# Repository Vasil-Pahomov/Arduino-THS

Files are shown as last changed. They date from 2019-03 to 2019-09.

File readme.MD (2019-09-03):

# General
This is Arduno-based air quality sensor and logger.
The following air quality parameters are measured:
- Temperature
- Humidity
- CO2 level
- total volatile organic compound (TVOC) level
- particle matter (dust) PM1.0, PM2.5 and PM10 levels

It can be powered either with batteries (I used 18560 recharge lithium) or with USB power supply.
The sensor stores data on MicroSD card and is able to download it to companion application with Bluetooth. An Android companion is designed: https://github.com/Vasil-Pahomov/AQS-Android or https://github.com/AlexeyKatsuro/ABTEx

# Circuit
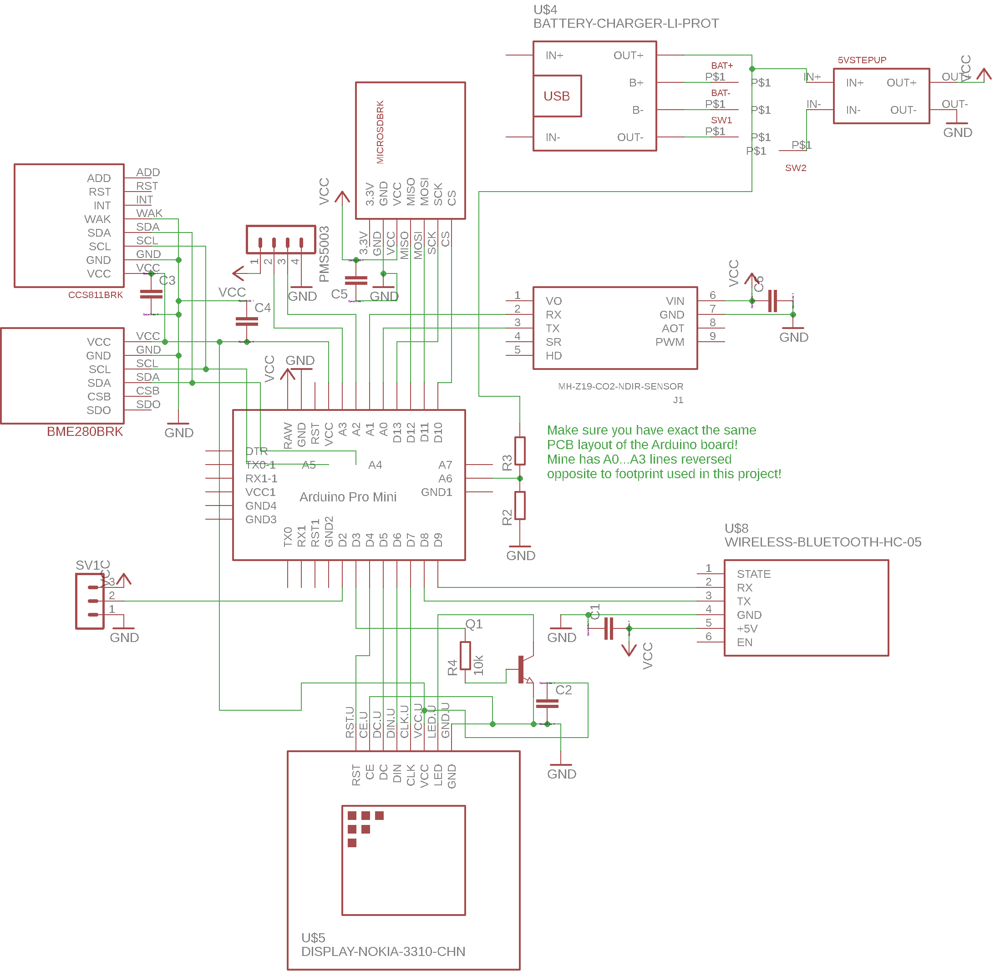
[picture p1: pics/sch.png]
Circuit diagram


# Part list

| Part | Image |
| ---- | ----- |
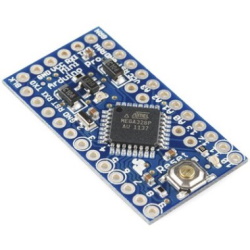
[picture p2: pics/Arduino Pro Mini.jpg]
| Arduino Pro Mini (3.3V) |  |
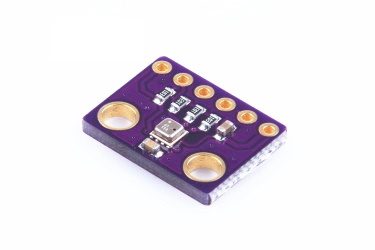
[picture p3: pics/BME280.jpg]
| BME280 temperature and humidity sensor board |  |
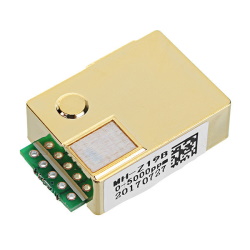
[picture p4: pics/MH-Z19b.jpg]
| MH-Z19B CO2 sensor |  |
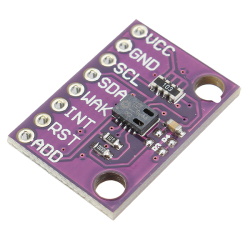
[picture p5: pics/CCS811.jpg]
| CCS811 TVOC sensor board |  |
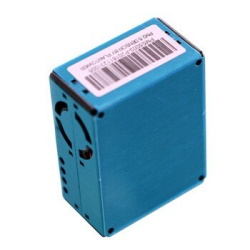
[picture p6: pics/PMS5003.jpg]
| PMS5003 dust sensor |  |
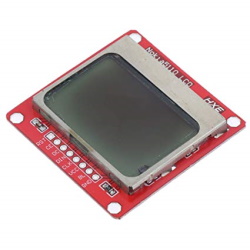
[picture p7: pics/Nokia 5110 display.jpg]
| Nokia 5110 LCD |  |
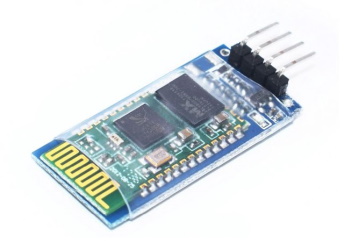
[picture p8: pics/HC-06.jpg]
| HC-06 bluetooth board |  |
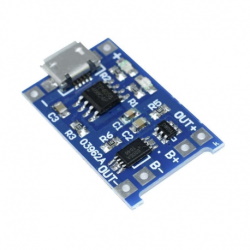
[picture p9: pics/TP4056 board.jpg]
| TP4056 charger board |  |
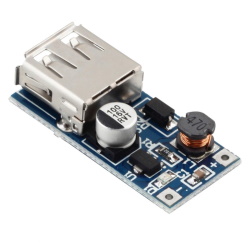
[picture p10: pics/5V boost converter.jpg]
| 5V boost converter |  |

# Log file format
Files are numbered starting from 0.log. Each file 10000 records. Record structure is defined in SDLog.h.
Once file numbers overcome 4000, it starts to delete files from the beginning.
Number of current file being written is stored in file named 'i' (2-byte unsigned word)

# Protocol format
## General
Organized as asyncronous messaging protocol. That is, both phone and sensor can send messages to each other. In fact, some messages resemble classis client-server communication.
## Message structure
| Field | Bytes | Description |
| ----- | ----- | --- |
| SGN | 2 | Signature=0xDEAF  |
| TYPE | 1 | Message type |
| DATA | ? | Message data, length depends on message type |

## Phone messages
### Sync time
TYPE=0x00
Sends current time to the sensor for sync up

| Field | Bytes | Description |
| ----- | ----- | --- |
| TIME | 4 | Unix timestamp |

### Read data
TYPE=0x01
Triggers sending data from the sensor

| Field | Bytes | Description |
| ----- | ----- | --- |
| FROMIDX | 4 | Index of starting record to read (including) |
| TOIDX | 4 | Index of ending record to read (including) |

### Reset storage
TYPE=0x02
Resets the storage (starts writing storage data anew)

The command has no body

### Calibrate CO2 sensor
TYPE=0x03
Sends calibration command to CO2 sensor. The sensor MUST be at least 20 minutes at open air environment (400 PPM).

The command has no body

## Sensor messages
### Status
TYPE=0x00

| Field | Bytes | Description |
| ----- | ----- | --- |
| STAT | 1 | Status:  0x00 if everything is OK, detailed see below |
| BAT | 1 | Battery percentage |
| LOGIDX | 4 | Number of last logged record (sequential, never overflows), returns 0xFFFFFFFF when there's SD card error |
| DATA | sizeof(Data) | Last sensor readings, Data structure |

#### Status byte
Zero value means OK, one - failure

| Bit | Description |
| ----- | --- |
| 0 | BME sensor |
| 1 | MH-Z19 sensor |
| 2 | PMS5003 sensor |
| 3 | CCS811 sensor |
| 4 | SD card |
| 5 | Time was synchronized |
| 6 | RESERVED (always 0) |
| 7 | RESERVED (always 0) |

### Data
| Field | Bytes | Description |
| ----- | ----- | --- |
| FROMIDX | 4 | Index of starting record |
| TOIDX | 4 | Index of ending record (including) |
| DATA | sizeof(Data)*N | Data records, N=TOIDX-FROMIDX |

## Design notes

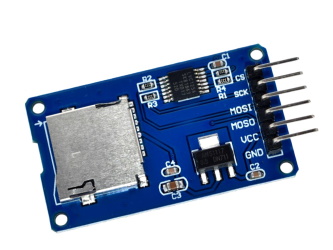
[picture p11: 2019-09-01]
pics/MicroSD slot.jpg

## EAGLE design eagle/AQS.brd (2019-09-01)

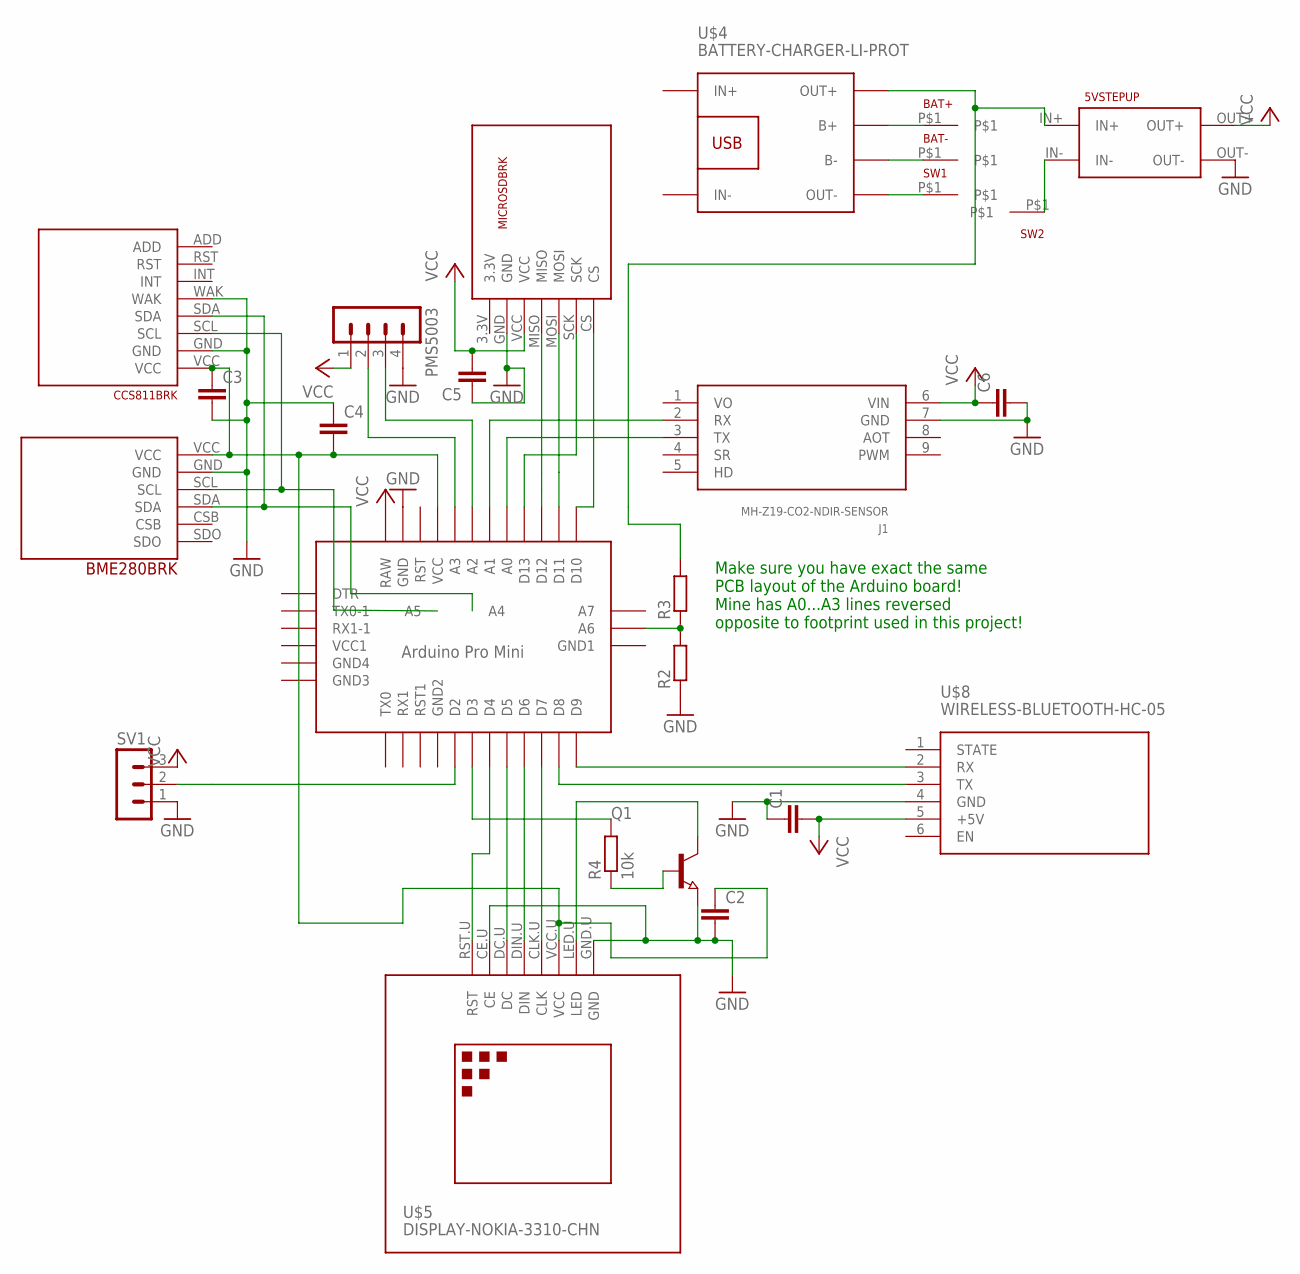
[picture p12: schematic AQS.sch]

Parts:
BAT+: PIN
BAT-: PIN
C1, C2, C3, C4, C5, C6: CC1206; C1206
J1: MH-Z19-CO2-NDIR-SENSOR; MH-Z19
PMS5003: MA04-1
Q1: NPN-TRANSISTOR_SOT23; SOT23
R2, R3: R-EU_0207/10; 0207/10
R4: 10k; 0207/10
SV1: MA03-1
SW1, SW2: PIN
U$1: ABK-PRO-MINI
U$2: BME280BRK
U$3: 5VSTEPUP
U$4: BATTERY-CHARGER-LI-PROT
U$5: DISPLAY-NOKIA-3310-CHN
U$6: CCS811BRK
U$7: MICROSDBRK
U$8: WIRELESS-BLUETOOTH-HC-05

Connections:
3.3V: U$7.3.3V
33V: C2.1, C3.1, C4.2, U$1.VCC, U$2.VCC, U$5.VCC.U (VCC), U$6.VCC
GND: C1.1, C2.2, C3.2, C4.1, C5.1, C6.2, J1.7 (GND), PMS5003.4, Q1.2 (E), R2.1, SV1.1, U$1.GND, U$2.GND, U$3.OUT-, U$5.CE.U (CE), U$5.GND.U (GND), U$6.GND, U$6.WAK, U$7.GND, U$8.4 (GND)
unnamed: BAT+.P$1, U$4.B+
unnamed: BAT-.P$1, U$4.B-
unnamed: R3.2, U$3.IN+, U$4.OUT+
unnamed: SW2.P$1, U$3.IN-
unnamed: U$1.A4, U$2.SDA, U$6.SDA
unnamed: U$1.A5, U$2.SCL, U$6.SCL
unnamed: U$1.D7, U$5.CLK.U (CLK)
unnamed: U$1.D6, U$5.DIN.U (DIN)
unnamed: U$1.D5, U$5.DC.U (DC)
unnamed: U$1.D4, U$5.RST.U (RST)
unnamed: Q1.3 (C), U$5.LED.U (LED)
unnamed: SW1.P$1, U$4.OUT-
unnamed: U$1.D9, U$8.2 (RX)
unnamed: U$1.D10, U$7.CS
unnamed: U$1.D11, U$7.MOSI
unnamed: U$1.D12, U$7.MISO
unnamed: U$1.D13, U$7.SCK
unnamed: J1.3 (TX), U$1.A0
unnamed: J1.2 (RX), U$1.A1
unnamed: U$1.D8, U$8.3 (TX)
unnamed: SV1.2, U$1.D2
unnamed: PMS5003.3, U$1.A2
unnamed: PMS5003.2, U$1.A3
unnamed: R2.2, R3.1, U$1.A6
unnamed: Q1.1 (B), R4.1
unnamed: R4.2, U$1.D3
VCC: C1.2, C5.2, C6.1, J1.6 (VIN), PMS5003.1, SV1.3, U$1.RAW, U$3.OUT+, U$7.VCC, U$8.5 (+5V)
VO: J1.1 (VO)

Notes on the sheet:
Make sure you have exact the same PCB layout of the Arduino board! Mine has A0...A3 lines reversed opposite to footprint used in this project!

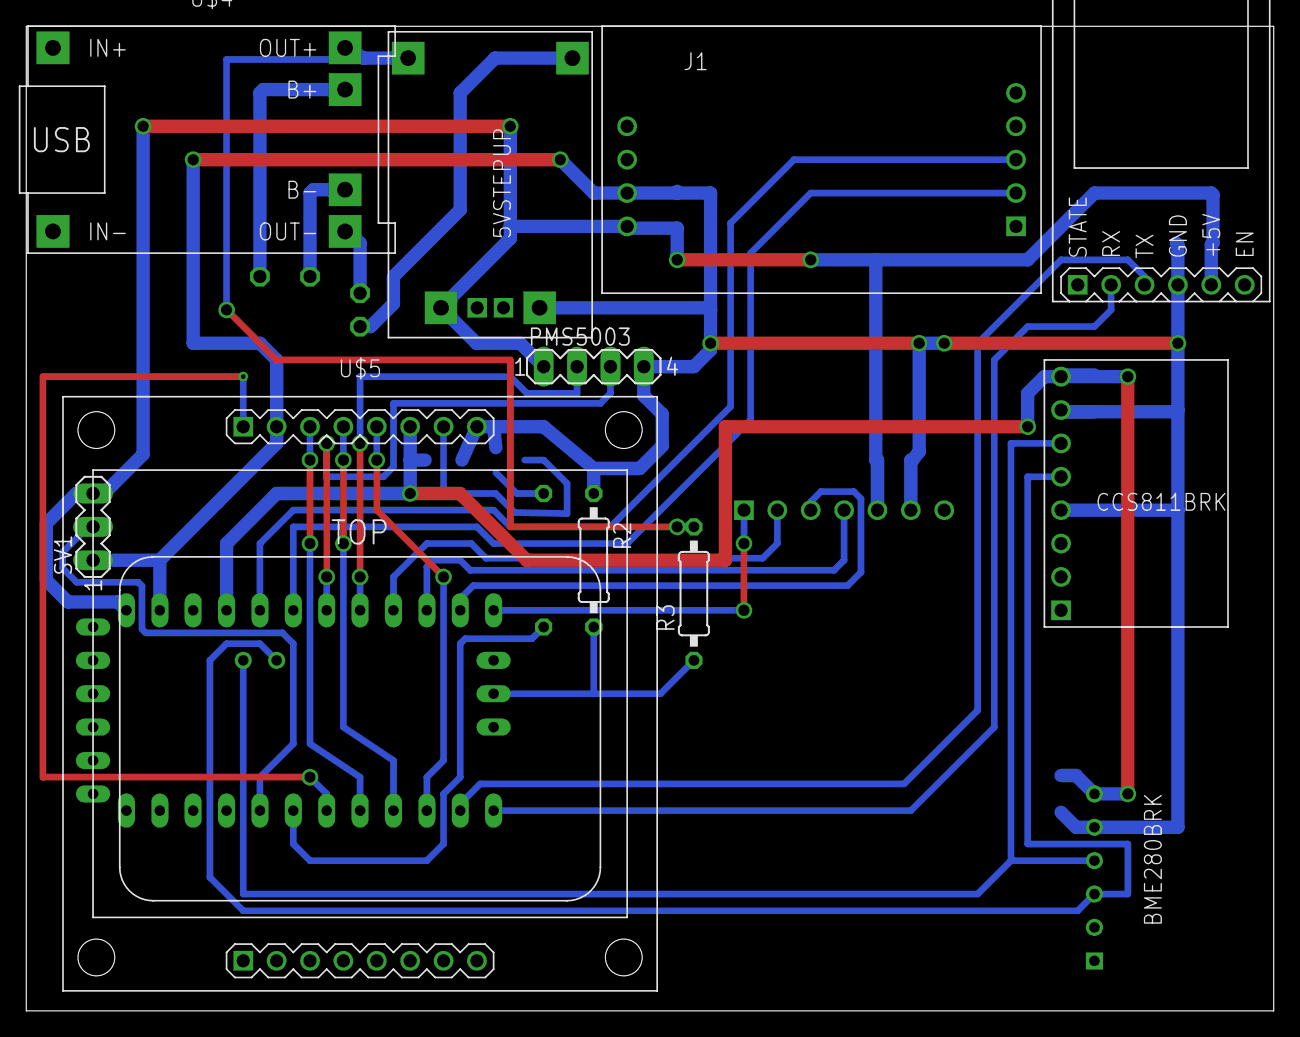
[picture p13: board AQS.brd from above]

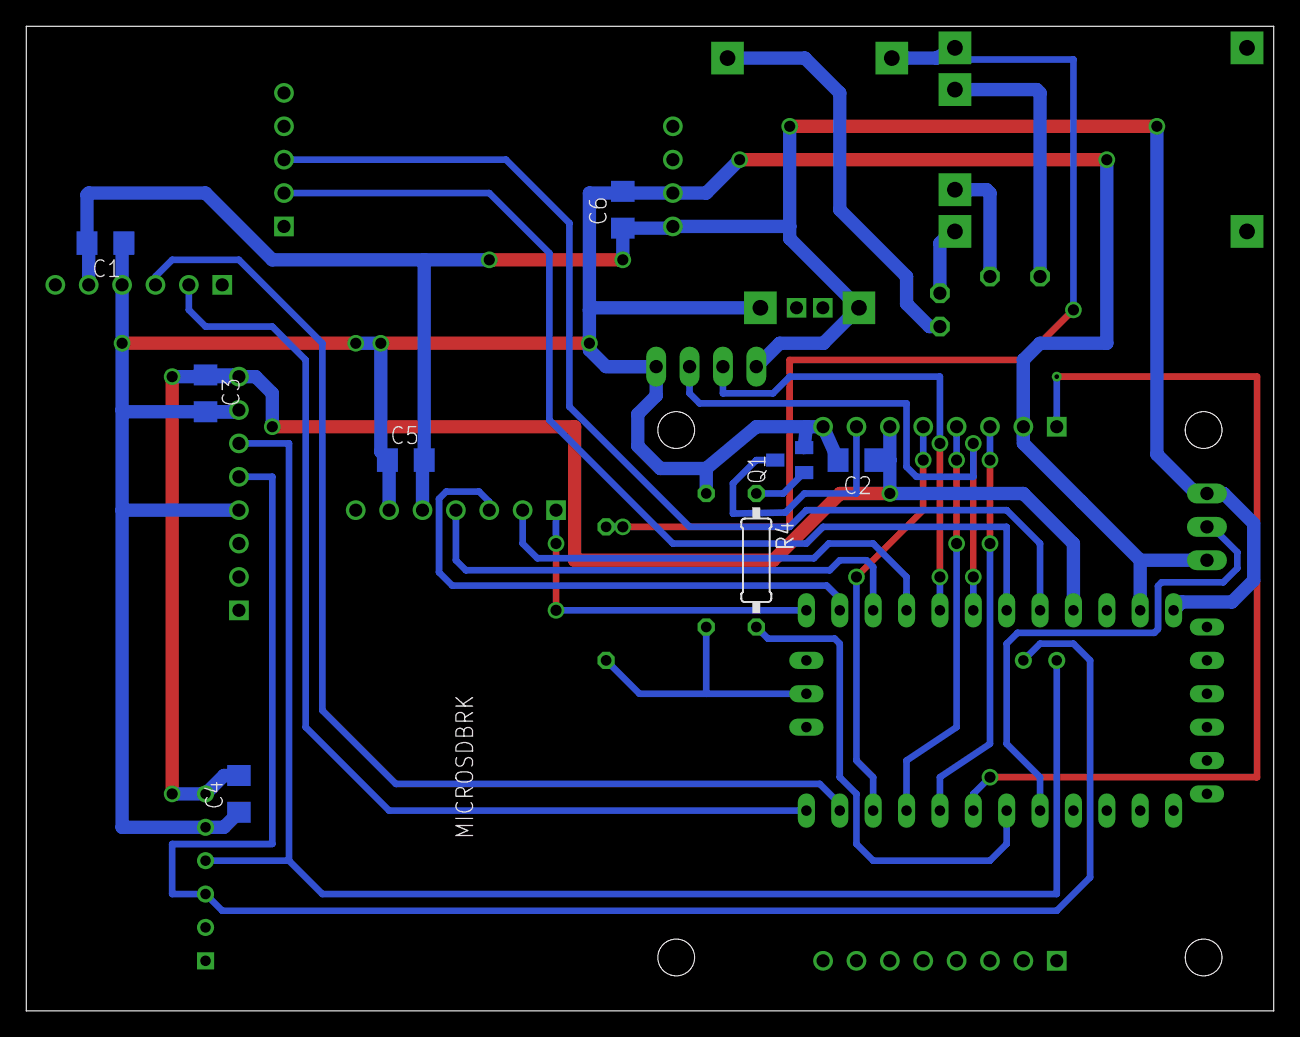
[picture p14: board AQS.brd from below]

Board: 2 copper layers, 94.9 x 74.9 mm, 25 parts (9 on the bottom side), 29 nets.

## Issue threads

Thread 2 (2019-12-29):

Wrong behavior when more that 65535 records are stored

Vasil-Pahomov, 2019-12-29:
Sensor sends incorrect dlog index reading - seems like two higher bytes are lost

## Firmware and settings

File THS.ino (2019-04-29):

#include <Adafruit_BME280.h> // 209 bytes (273 bytes with init and read)

#include <SoftwareSerial.h> //one SoftwareSerial uses 126 bytes on clean sketch, two - 157 bytes
#include <SPI.h>
#include <PCD8544.h>
#include <Adafruit_CCS811.h>
#include <time.h>

#include "SDLog.h"

#include "mh_z19.h"
#include "pms5003.h"

#define DEBUG
#define READ_INTERVAL_MS 20000
#define BT_TIMEOUT_MS 2000
#define BACKLIGHT_PIN 3

byte buf[32];

SoftwareSerial btSerial(8,9);
Adafruit_BME280 bme;
Adafruit_CCS811 ccs;


//clock, data-in, data select, reset, enable
PCD8544 lcd(7,6,5,4,A7);

DLog dlog;

uint32_t lastms;//last millis() data was read, used to track intervals between readings
uint32_t long rtimebase;//UNIX time of sensor start, calculates every time STATUS command is received
uint8_t rcmdlen;//length of currently receiving command
uint32_t lastmsbt;//last millis() BT was read, used to track BT timeout
int batcnt;//counter of battery measurements during "idle" cycle
long batacc;//"accumulator" of battery measurements

tm timestruct;


void setup() {
  analogWrite(BACKLIGHT_PIN,255);

  // PCD8544-compatible displays may have a different resolution...
  lcd.begin(84, 48);
  lcd.setCursor(0, 0);
  lcd.print(F("Init: serial"));

  Serial.begin(9600); //engaging Serial uses 168 bytes on clean sketch

  
  lcd.setCursor(0, 1);
  lcd.print(F("Init: CO2"));

  //todo: check for MH setup error
  mh_setup();

  pinMode(LED_BUILTIN, OUTPUT);
  analogReference(INTERNAL);
  pinMode(A6, INPUT);

  lcd.setCursor(0, 2);
  lcd.print(F("Init: temp&hum"));

  if (!bme.begin(0x76)) {
    lcd.setCursor(0, 0);
    lcd.print(F("BMP Error!"));
    digitalWrite(LED_BUILTIN, HIGH);
    delay(10000);
    lcd.clear();
  }

  lcd.setCursor(0, 3);
  lcd.print(F("Init: VOC"));

  if(!ccs.begin()){
    lcd.setCursor(0, 0);
    lcd.print(F("CCS Error!"));
    delay(10000);
    lcd.clear();
  }

  ccs.setDriveMode(CCS811_DRIVE_MODE_10SEC);

  lcd.setCursor(0, 4);
  lcd.print(F("Init: PM"));
  //todo: check for PMS setup error
  pms_setup();
  analogWrite(BACKLIGHT_PIN,10);
  lcd.setCursor(0, 5);
  lcd.print(F("Init done"));

  lastms = 0;
  btSerial.begin(9600);

}

void commandSync() {
  uint32_t * rtime = (uint32_t*) (buf + 3);
  rtimebase = *rtime - millis()/1000;
#ifdef DEBUG
  Serial.print(F("Got time:"));Serial.println(*rtime); 
#endif   
}

void loop() {
  btSerial.listen();
  batcnt = 0;
  batacc = 0;
  while (lastms != 0 && (millis() < lastms + READ_INTERVAL_MS)) {
    while (btSerial.available() > 0)
    {
      buf[rcmdlen++] = btSerial.read();
#ifdef DEBUG
      Serial.print(F("B("));Serial.print(rcmdlen-1);Serial.print(F(")="));Serial.print(buf[rcmdlen-1]); Serial.print(':');Serial.println((char)buf[rcmdlen-1]); 
#endif        
      if (rcmdlen == 1) { //looking for the beginning of the command
        if (buf[0] != 0xDE) {
          rcmdlen = 0;  
#ifdef DEBUG
          Serial.print(F("BT: invalid sign 1st byte: "));Serial.println(buf[0]); 
#endif        
          continue;
        }
      } else if (rcmdlen == 2) {
        if (buf[1] != 0xAF) {
          rcmdlen = 0;
#ifdef DEBUG
          Serial.print(F("BT: invalid sign 2nd byte: "));Serial.println(buf[1]); 
#endif        
          continue;
        } 
      } else {
      //command received (may be partially)
        
        switch (buf[2]) {
          case 0:
            if (rcmdlen>=7) {
              commandSync();
              rcmdlen = 0;
              lastms = millis() - READ_INTERVAL_MS;
            }
            break;
          case 1:
            if (rcmdlen>=11) {
              if (rtimebase !=0) {
                sdTransmitData();
                lastms = millis() - READ_INTERVAL_MS;
              } else
              {
#ifdef DEBUG
                Serial.print(F("No sync - no transmission"));
#endif        
              }
              rcmdlen = 0;
            }
            break;
          case 2:
            if (rcmdlen>=3) {
              sdReset();
              rcmdlen = 0;
              lastms = millis() - READ_INTERVAL_MS;
          }
            break;
          case 3:
            if (rcmdlen>=3) {
              mh_calibrate();
              rcmdlen = 0;
              lastms = millis() - READ_INTERVAL_MS;
            }
            break;
          default:
#ifdef DEBUG
            Serial.print(F("BT: command code error "));Serial.println(buf[2]);
#endif        
            rcmdlen=0;
          break;
        }
      }
   
      
      lastmsbt = millis();
    }
    if (rcmdlen > 1 && millis() > lastmsbt + BT_TIMEOUT_MS) {
      //timeout receiving command, reverting
#ifdef DEBUG
        Serial.print(F("BT: command timeout at length "));Serial.println(rcmdlen); 
#endif        
        rcmdlen = 0;  
    }    
    batacc += analogRead(A6);
    batcnt++;
    delay(100);
  }
  lastms = millis();
  
  digitalWrite(LED_BUILTIN, HIGH);

  float bmeTemp = bme.readTemperature();
  float bmeHum = bme.readHumidity();

  unsigned int ppm = mh_getPPM();
  
  ccs.setEnvironmentalData((int)bmeHum, bmeTemp);
  int ppb = -3;//data not available
  int eCO2 = -3;
  if(ccs.available()){
    if (!ccs.readData()) {
      eCO2 = ccs.geteCO2();
      if (eCO2 != 0) {
        ppb = ccs.getTVOC();
      } else {
        ppb = -1;//eCO2=0, warming up
      }
    } else 
    {
      ppb = -2;//data not read
    }
      
  }

  pms_read();

  //950 - 100%
  //700 - 0% (на 5 минут)
  int acc;
  if (batcnt == 0) {
    acc = 255;
  } else {
    acc=(batacc/batcnt-700)*2/5;
    if (acc > 100) acc = 100;
    if (acc < 0) acc = 0;
  }
  

  lcd.clear();
  digitalWrite(LED_BUILTIN, LOW);

  lcd.setCursor(0, 0);
  lcd.print(bmeTemp);lcd.print('C');
  lcd.setCursor(42, 0);
  lcd.print(bmeHum);lcd.print('%');
  lcd.setCursor(0, 1);
  lcd.print(ppm);lcd.print('@');
  lcd.setCursor(42, 1);
  lcd.print(ppb);lcd.print('#');
  lcd.setCursor(0, 2);
  lcd.print(pms_pm1_cf1); lcd.print(' '); lcd.print(pms_pm2_5_cf1); lcd.print(' '); lcd.print(pms_pm10_cf1); lcd.print('*');


  if (rtimebase != 0) {
    time_t ttime = rtimebase + millis()/1000 - UNIX_OFFSET;
    gmtime_r(&ttime, &timestruct);
    isotime_r(&timestruct, (char*)buf);
    buf[10]=0;//separate date from time
    lcd.setCursor(0, 3);
    lcd.print((char*)(buf+11));//time
    lcd.setCursor(0, 4);
    lcd.print((char*)buf);//date
  }

  if (acc != 255) {
    lcd.setCursor(0, 5);
    lcd.print('B');lcd.print(acc);lcd.print('%');
  }


  dlog.ssecs = millis()/1000;
  dlog.rtime = rtimebase != 0 ? rtimebase + dlog.ssecs : 0;
  dlog.data.temp = bmeTemp*100;
  dlog.data.hum = bmeHum*100;
  dlog.data.co2 = ppm;
  dlog.data.pm1 = pms_pm1_cf1;
  dlog.data.pm25 = pms_pm2_5_cf1;
  dlog.data.pm10 = pms_pm10_cf1;
  dlog.data.tvoc = ppb;

  writeLog(&dlog);

  //writing binary data to the bluetooth
  
  buf[0] = 0xDE; //signature
  buf[1] = 0xAF;
  buf[2] = 0;    //command code
  buf[3] = 0;    //status
  buf[4] = acc;   //battery
  btSerial.write(buf,5);
  delay(50);  //not sure why these delays are needed... but there's sometimes garbage in BT channel otherwise
  btSerial.write((byte*)&lastLogIdx, 4); //log index
  delay(50);  
  btSerial.write((byte*)&dlog.data, sizeof(Data)); //data
  
  /**/
}

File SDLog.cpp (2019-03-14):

#include <SPI.h>
#include <SD.h>
#include <SoftwareSerial.h>
#include "global.h"
#include "SDlog.h"

#define SD_CS_PIN 10 //CS pin of the SD card
#define INDEX_FILE_NAME F("i")
#define RECS_PER_FILE 1000 //records per file
#define MAX_FILES_COUNT 4000 //this results in less than 1 gig in the total files size and stores data for 10 years of continous operation - seems appropriate
#define DEBUG

File file;
//number of current file being written, initial value means it's not initialized yet
uint16_t curFileNum = 0xFFFF;
uint32_t lastLogIdx = 0xFFFFFFFF;

bool updateIndexFile()
{
  SD.remove(INDEX_FILE_NAME);
  file = SD.open(INDEX_FILE_NAME, FILE_WRITE);
  if (!file) {
#ifdef DEBUG
    Serial.println(F("SD: error index writing"));
#endif      
    return false;
  }
  file.write((uint8_t*)&curFileNum,2);
  file.close(); 
  return true;
}

bool ensureInit() {
  if (curFileNum == 0xFFFF) {
#ifdef DEBUG
      Serial.println(F("SD: initializing"));
#endif
    if (!SD.begin(SD_CS_PIN)) {
#ifdef DEBUG
      Serial.println(F("SD: init error"));
#endif
      return false;
    }

    if (!SD.exists(INDEX_FILE_NAME)) {
#ifdef DEBUG
      Serial.println(F("SD: no index file, initializing"));
#endif
      curFileNum = 0;
      if (!updateIndexFile()) {
        return false;
      }
    } else {
#ifdef DEBUG
      Serial.println(F("SD: read index file"));
#endif
      file = SD.open(INDEX_FILE_NAME, FILE_READ);
      if (!file) {
#ifdef DEBUG
        Serial.println(F("SD: error index reading"));
#endif      
        return false;
      }
      file.read(&curFileNum,2);
      file.close(); 
#ifdef DEBUG
      Serial.print(F("SD: index read:"));Serial.println(curFileNum);
#endif
    }
  }
  return true;
}

bool writeLog(DLog* rec)
{
  if (!ensureInit()) {
    return false;
  }
  String fname = String(curFileNum);
  long filesize = 0;
  if (SD.exists(fname)) {
    file = SD.open(fname,FILE_READ);
    if (!file) {
  #ifdef DEBUG
      Serial.print(F("SD: error opening log "));Serial.println(curFileNum);
  #endif      
      return false;
    }
    filesize = file.size();
    file.close();
    if (filesize >= sizeof(DLog)*RECS_PER_FILE) {
      //assume file counter never overruns. once data is written every 10 seconds and single file has 10000 records, 16-bit number should overrun in almost 200 years of continous operation
      curFileNum++;
      fname = String(curFileNum);
      if (SD.exists(fname)) {
        SD.remove(fname);
      }
      filesize = 0;
  #ifdef DEBUG
      Serial.print(F("SD: increasing file count to "));Serial.println(curFileNum);
  #endif      
      if (!updateIndexFile()) {
        return false;
      }
  #ifdef DEBUG
      Serial.print(F("SD: checking file count "));Serial.print(curFileNum);Serial.print('/');Serial.println(MAX_FILES_COUNT);
  #endif           
      if (curFileNum >= MAX_FILES_COUNT) {
  #ifdef DEBUG
      Serial.print(F("SD: removing tail file "));Serial.println(curFileNum - MAX_FILES_COUNT);
  #endif       
        if (!SD.remove(String(curFileNum - MAX_FILES_COUNT))) {
  #ifdef DEBUG
      Serial.println(F("SD: error removing tail file"));
  #endif      
        }
      }
    }//end if file overrun
  }//end if file exists
  file = SD.open(fname,FILE_WRITE);
  if (!file) {
#ifdef DEBUG
    Serial.print(F("SD: error writing log "));Serial.println(curFileNum);
#endif      
    return false;
  }
  file.write((uint8_t*)rec, sizeof(DLog));
  file.close(); 

  lastLogIdx = curFileNum * RECS_PER_FILE + filesize / sizeof(DLog);
#ifdef DEBUG
  Serial.print(F("SD: written rec #"));Serial.print(lastLogIdx);Serial.print(F(" to file #"));Serial.println(curFileNum);
#endif      
  
  return true;
}

//resets file number so that all previous content of SD card starts being overwritten anew
void sdReset() {
  curFileNum = 0;
  updateIndexFile();
  String fname = String(curFileNum);
  if (SD.exists(fname)) {
    SD.remove(fname);
  }
#ifdef DEBUG
  Serial.println(F("SD: reset done "));
#endif      
}

void sdTransmitData() {
  uint32_t cIdx = *((uint32_t*) (buf + 3));
  uint32_t toIdx = *((uint32_t*) (buf + 7));
  
  int fileIdx = cIdx / RECS_PER_FILE;
  int recIdx = cIdx % RECS_PER_FILE;
#ifdef DEBUG
  Serial.print(F("SD: read data request"));Serial.print(cIdx);Serial.print('-');Serial.print(toIdx);Serial.print(F(", file/rec="));Serial.print(fileIdx);Serial.print('/');Serial.println(recIdx);
#endif

//once I uncomment one of these lines below, the receiving data by bluetooth stops working!
//I don't know WTF is here
  if (lastLogIdx == 0xFFFFFFFF) {
#ifdef DEBUG
//  Serial.println(F("SD: read data request rejected, no data (yet)"));
#endif
//    return;
  }

  lcd.clear();
  btSerial.write(buf,11);

  long lastmst = millis() - 10000;

  bool firstRecord = true;
  String fname = String(fileIdx);
  while (cIdx <= toIdx) {
    if (firstRecord) {
      // the very first record for transmitting
#ifdef DEBUG
//        Serial.print(F("SD: opening first file / at pos:"));Serial.print(fname);Serial.print('/');Serial.println(recIdx * sizeof(DLog));
#endif        
      file = SD.open(fname, FILE_READ);
      if (!file) {
#ifdef DEBUG
        Serial.print(F("SD: error opening file for transmitting: "));Serial.println(fname);
#endif        
        return;
      }
      if (!file.seek(recIdx * sizeof(DLog))) {
#ifdef DEBUG
        Serial.print(F("SD: error seeking file to "));Serial.println(recIdx * sizeof(DLog));
#endif        
        return;
      }
    } 
    firstRecord = false;

    //transmitting the record
    if (file.read(buf, sizeof(DLog))) {
      btSerial.write(buf, sizeof(DLog));
      if (millis() > lastmst + 500) {
        lcd.setCursor(0,0);
        lcd.print(cIdx);lcd.print('/');lcd.print(toIdx);
        lastmst = millis();
      }
    } else {
#ifdef DEBUG
        Serial.print(F("SD: error reading file "));Serial.println(fname);
#endif        
      return;
    }
    recIdx++;
    if (recIdx >= RECS_PER_FILE) {
      //jumping to the next file
      file.close();
      fileIdx++;
      fname = String(fileIdx);
      file = SD.open(fname, FILE_READ);
      recIdx = 0;
#ifdef DEBUG
//      Serial.print(F("SD: Jumping to next file "));Serial.println(fname);
#endif        
    }
    
    cIdx++;
  }
  file.close();
#ifdef DEBUG
//  Serial.println(F("SD: Transmission done "));
#endif        
}

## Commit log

2018-06-22 sample version with bme sensor
2018-09-04 Added support for PMS5003 sensor
2018-09-05 fixes and improvements to PMS5003
    [pms5003.cpp]
2018-10-24 Operational version with logging and beginning of BT protocol implementation. Some wiring changes for MH_Z19 and PMS5003 due to actual PCB layout
2019-01-25 Added reset storage cmd
    [SDLog.cpp, THS.ino]
2019-01-29 Fix data transfer, some refactoring Some fu..n magic is in SDLog.cpp, but it works
    [SDLog.cpp, THS.ino]
2019-01-29 Fix index file write (for some reason it wasn't overwritten but appended)
    [SDLog.cpp]
2019-01-29 Updated to 1000 records/file, fixed some warnings ...and this made BT receiving work again (the same WTF magic)
    [SDLog.cpp, THS.ino]
2019-02-06 Working data transmission with progress indication Increased measurement interval to 20 secs (avoid periodic TVOC drops at 10 sec)
    [SDLog.cpp, THS.ino]
2019-03-14 Added CO2 calibration command
2019-03-14 Added calibration command (at a cost of nice glyphs) Also removed LED handling that was already commented out
2019-04-24 Multiple battery measurements averaged - more steady battery percentage readings
2019-04-29 Battery level tuned
2019-09-01 schematic image, eagle project files and libraries
    [AQS.brd, AQS.sch]
